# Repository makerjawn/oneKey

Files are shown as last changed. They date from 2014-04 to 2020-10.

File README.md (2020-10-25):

jawnWare: oneKey (obsolete, check forked)
===========

jawnWare_8 

Project Focus
-------------------
Developing a low-cost (<$2) and accessible derivative of the MaKey MaKey so that it can be sustainably deployed via workshops at various library branches. 

The aim is to introduce youth in underserved/low-income communities to making hardware that they can then tinker/play/make with. It's adressing the question "Can I take this home?" and the inability for youth to use take projects using digital media tools such as the MaKey MaKey home.

In participating in this process we hope for them to take more ownership of their tools. We're also trying to adress wether or not the library and its participants can make their own tools for learning via desktop manufacturing and production methods.

So what is a MaKey MaKey?
-------------------
From Sparkfun's [*MaKey MaKey Documentation*](https://github.com/sparkfun/makeymakey):

*"Using the MaKey MaKey you can make anything into a key (get it?) just by connecting a few alligator clips. The MaKey MaKey is an invention kit that tricks your computer into thinking that almost anything is a keyboard. This allows you to hook up all kinds of fun things as an input."*

**How does it work?**

*"The MaKey MaKey uses high resistance switching to detect when you've made a connection even through materials that aren't very conductive (like leaves, pasta or people). This technique attracts noise on the input, so a moving window averager is used to lowpass the noise. The on-board ATMega32u4 communicates with your computer using the Human Interface Device (HID) protocol which means that it can act like a keyboard or mouse."*

Methods
-------------------
The original oneKey uses a vinyl cutter and 3M copper tape to make a low-barrier and low-cost method for creating traces to solder onto. If working indoors take precautions with ventilalation etc. Working currently on a PCB kit version.

Need for the oneKey
-------------------
* 3M Copper Tape (used to be much cheaper, working on a thinner tape iteration.) ([Buy](http://www.amazon.com/inch-yds-Copper-Foil-Tape/dp/B00CBPM9RY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) | [HowTo](http://www.kobakant.at/DIY/?p=1132))
* Attiny85 ([Buy](http://www.digikey.com/product-detail/en/0/ATTINY85-20PU-ND) | [HowTo](about:blank))
* Attiny85 Standoff/ IC DIP Socket([Buy](http://www.digikey.com/product-detail/en/0/ATTINY85-20PU-ND) | [HowTo](about:blank))
* Resistors: 2x [68 ohm](http://www.digikey.com/product-detail/en/0/S68HCT-ND) , 1x [1.5K](http://www.digikey.com/product-detail/en/0/S1.5KHCT-ND), 1x [1M ohm](http://www.digikey.com/product-detail/en/0/CF14JT1M00CT-ND).
* Zener Diode ([Buy](http://www.digikey.com/product-detail/en/0/1N4148DICT-ND) | [HowTo](about:blank))
* USB Cable ([Buy](http://www.amazon.com/Eversame-Colorful-Hi-Speed-Universal-Phones-Black/dp/B00OC6WR22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) | [HowTo](about:blank))
* Vinyl Cutter (All makes/models work) ([Buy](http://www.amazon.com/Vinyl-Cutter-USCutter-34in-BUNDLE/dp/B00CDQGCTW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) | [HowTo](about:blank))
* Soldering Iron ([Buy](about:blank) | [HowTo](about:blank))
* Needle Nose Pliers ([Buy](about:blank) | [HowTo](about:blank))
* Wire Cutter ([Buy](about:blank) | [HowTo](about:blank))
* Wire Stripper ([Buy](about:blank) | [HowTo](about:blank))
* Tiny AVR Programmer or Equivalent ([Buy](https://www.sparkfun.com/products/11801) | [HowTo](https://learn.sparkfun.com/tutorials/tiny-avr-programmer-hookup-guide/))

Repository Contents
-------------------
* **/Firmware** - Arduino Files+
* **/Hardware** - All design files (EAGLE, FRITIZING, AI+)
* **/Instructon** - Instructors materials
* **/Supplies** - Previous part orders

Variations
----------------
**Vinyl Cut Copper Tape** 

oneKey Vinyl 

This build requres soldering and takes an hour to construct. The tape can be tricky to adhere to a substrate, but for all intents and purposes IT WORKS!

Requires the installation of the Digispark Arduino IDE to upload and run code from /Firmware.
All vector files needed for vinylcutting reside in /Hardware.

**PCB(REV.1)**  

PCB

PCB2

Looking to make a PCB kit, currently waiting for PCB to be milled. See the Eagle Schematics and Board files in /Hardware.

**Quick-build(Still in Development)**  
This build is solderless, can be built in less than an hour.

Links/Sources
-------------------
* [Digispark](http://digistump.com/products/1)
* [Digispark IDE](about:blank)
* [Digispark Clone](about:blank)
* [BhavyaShukla - Makey-makey-using-arduino-uno-r3-Multiple-input](https://github.com/BhavyaShukla/Makey-makey-using-arduino-uno-r3-Multiple-inputs-)
* [Moving Avarage Library](https://github.com/BhavyaShukla/Makey-makey-using-arduino-uno-r3-Multiple-inputs-)
* [JoyLab's/Sparkfun's - MaKey MaKey](https://github.com/sparkfun/makeymakey)
* [avrdude tutorials](https://learn.adafruit.com/usbtinyisp/avrdude)

toDo
-------------------
* easier peeling
* solderless
* remove usb cable
* ~~thruhole prototype~~
* non-digispark
* attiny45?
* find other hardware thruhole prototype
* do outreach, find other ppl who want this

brief history
-------------------
To date two iterations of the one input MaKey MaKey derivative, "MaKey MaKey MaKey", or officially "oneKey" for short, have been deployed. The first generation proved that youth could make, hack, and play with their own hardware. After various form and material explorations as well as a circuit redesign it is currently in its second phase. The new design is easier to handle, the cost per unit has dropped from $7 to $1.30, it's quicker to make, and there is still much more to refine.

people
-------------------
* bk brandonklevence@gmail.com
* the Maker Jawn Initiative info@makerjawn.org

License Information
-------------------
The hardware is released under [Creative Commons Share-alike 3.0](http://creativecommons.org/licenses/by-sa/3.0/).  
All other code is open source hardware so please feel free to do anything you want with it; 
you buy me a beer if you use this and we meet someday ([Beerware license](http://en.wikipedia.org/wiki/Beerware)).
Please support [Digispark](https://github.com/sparkfun/makeymakey) and [JoyLabs](https://github.com/sparkfun/makeymakey) and buy their products if you decide to remix. Without their creativity and ingenuity this project would never have happened.

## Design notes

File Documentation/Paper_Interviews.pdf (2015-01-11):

Vince, age 9, a participant in my workshops at the Kensington Branch.

B So, What did we make?
V A MaKey MaKey, wooh!
B Cool right?
V Look at this, nobody knows how to do this..
B What did we put in it?
V Wires and wires, and wires .. And MaKey MaKey hot sauce(solder). B And then what did we use?
V A light. And then a long wire that plugs it into the computer. Ta DA! **Showing off the MaKey MaKey MaKey**
B So what’s going on here?
V When you touch the playdoh it does stuff on the computer.
B Do you remember what it’s doing?
V Being a keyboard!
**With minecraft the game on screen, he breaking down blocks of sand and digging a ditch. V The MaKey MaKey, it cuts!
V I am so happy to take this home and break my computer!
V Can we make another?
B No, you already have one dude!
V I want to make more, can I help other kids make them here? I should get my friends from school to come to make more MaKey MaKeys!

After playing a Canabalt with Ice cream where you lick your ice cream to interact with the game on screen.(using the MaKey MaKey)

B So what do you think?
O That’s pretty weird.
B What is weird about it?
O it's kinds weird because you're licking the ice cream...
B How did you control it?
O You moved it with your tongue. Your tongue is the controller. B What did you think about the game?
O It’s like Mario, but faster.

This is a video interview about a magnetic maze prototype we made at the Village of Arts and Humanites. Donnie filmed and helped correct or as questions of Mykal who was demonstrating his creation.

M Hi I’m Mike
B How old are you?
M I’m 8.
B Where do you live?
M On the north side of the street. B And what do we have here?
M We have a Magnetic Maze.
B Sweet.
M Now look, it might come off, but don’t be mad.
B Ok?
M Ya see, if I come to this playdoh here with the magnet, this light comes on and off? B So Mykal, can you explain the circuit to me, the positive and the negative?
M The yellow is the postitive.
D Posittive Mykal
M Yellow is posittive and red is negative.
B And what about the batter and LEDs?
M This is my LED (points to battery).
D No no!
M This is my LED and this is my battery.(correctly identifies)
B And what about your glasses?
M This is them! (points) They light up when you hit the maze.
D Basically its an LED light, and we have a Maze. So when you're playing the maze and you've hit a wall or something will glow of to signify you and notificate you that you've hit the wall. So we’ve made a sample and soon we’ll be able to make something like this, but huge. M Soon we’ll be able to make something else, like this!
B Cool!
D Yeah, what’s your name?
M I’m Mykal
B I’m bk.
D and I’m Donnie, we out!

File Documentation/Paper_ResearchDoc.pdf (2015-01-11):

Name:
bk // Brandon Klevence

Contact:
bklevence@uarts.edu // klevenceb@freelibrary.org @bklvnc // @makerjawn

Blog:
www.makerjawn.org

Links:
https://www.diigo.com/user/bklvnc

Area(s) of Interest:
Informal Education / Participatory Design of Interactive Installations
/ Getting people making with electronics

Contextual Brief:
I will be implementing young adult programming at the Kensington Free Library Branch while overseeing similar programming at that Parkway Central Branch. Our focus is to improve digital skills and literacy of our library-goers through guided learning, exploration, workshops, and eventually collaboration on participatory design projects. This is a second round of implementing this type of programming. We’re very interested in how to document our work and share it online. Specifically methods of getting our young-adults to document and talk about their own work.
My focus in particular will be creating kits to encourage exploration of various concepts and skills related to learning about and making electronic interactives or installations.

Keywords:
connected learning, digital literacy, electronics, making, maker, library, resources, underserved, after-school, teens, programming, computing, technology, understanding, play, exploration, workshops, etextiles, crafting, flat, teaching, guided learning, participatory design, eorigami, hi-low tech, mit, makered, digital media, internet, proficiency, sharing, collaborating, exposure, computation, programming, kids, youth, arts, craft, empowering, failure,

What am I looking for?
- peer reviewed research
- case studies
- other precedents of making in libraries
- educational kits for exploring topics/play
- scaffolded learning plans. see: (http://learn.sparkfun.com/)
- tools for guiding making/learning in workshops or public places
- suggestions for teaching different age groups, needs and best practices

Case, Amber. An Illustrated Dictionary of Cyborg Anthropology. N.p.: n.p., n.d.Http://cyborganthropology.com/store/. Web.
Dewey, John. Experience and Education. New York: Macmillan, 1938. Print.
Anderson, Chris. Makers: The New Industrial Revolution. New York: Crown Business, 2012. Print.
Rushkoff, Douglas, and Leland Purvis. Program or Be Programmed: Ten Commands for a Digital Age. Berkeley, CA: Soft Skull, 2011. Print.
Brosterman, Norman, and Togashi. Inventing Kindergarten. [New York, N.Y.]: H.N. Abrams, 1997. Print.
Murakami, Haruki, and Jay Rubin. Norwegian Wood. New York: Vintage International, 2000. Print.
Plowman, Lydia, Christine Stephen, and Joanna McPake. Growing up with Technology: Young Children Learning in a Digital World. London: Routledge, 2010. Print.

Itō, Mizuko. Hanging Out, Messing Around, and Geeking Out: Kids Living and Learning with New Media. Cambridge, MA: MIT, 2010. Print.

Nilsson, Elisabet M. "The Making of a Maker-space for Open Innovation, Knowledge Sharing, and Peer-to-peer Learning." FUTURE LEARNING SPACES. Helsinki: Aalto University, 2011. 293-98. Print.

Petrovich, Dushko, and Roger White. Draw It with Your Eyes Closed: The Art of the Art Assignment. Brooklyn, NY: Paper Monument, 2012. Print.

Allen, Felicity. Education. London: Whitechapel Gallery, 2011. Print.

https://pittsburghkids.org/exhibits/makeshophttp://www.libraryasincubatorproject.org/?p=11684

http://www.pensacolamesshall.org/explore/mess-kits/

Fellowship Forum/Blog:
http://www.hastac.org/

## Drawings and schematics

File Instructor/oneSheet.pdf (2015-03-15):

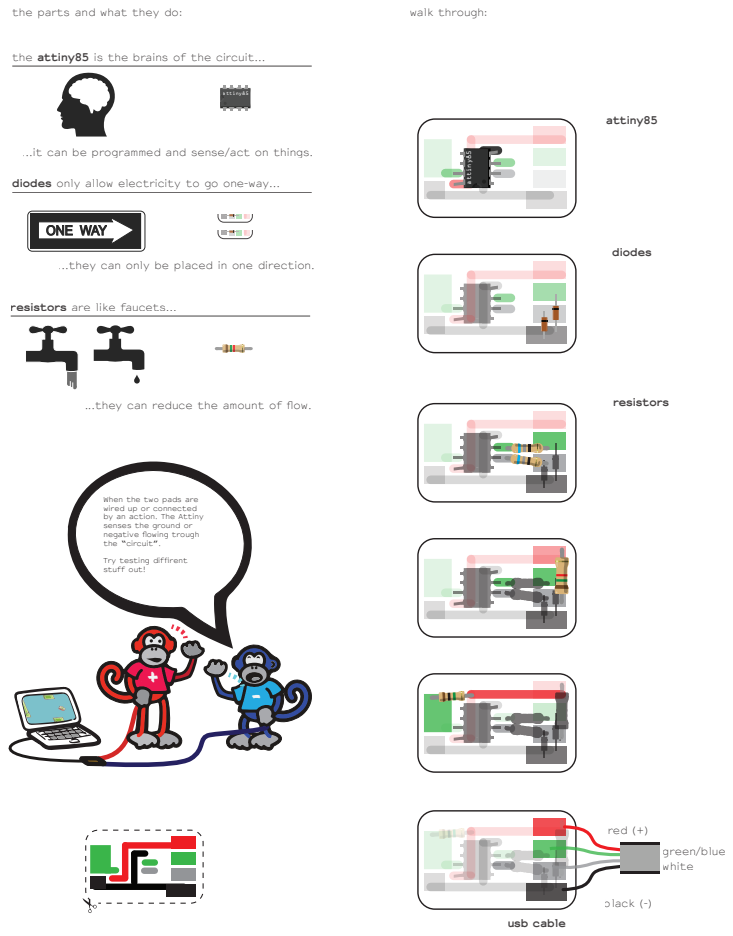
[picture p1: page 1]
ONE WAY; the parts and what they do:; walk through:; attiny85; attiny85 attiny85 attiny85 attiny85 attiny85; diodes; resistors; usb cable; black (-); red (+); green/blue white

the attiny85 is the brains of the circuit...

...it can be programmed and sense/act on things.

diodes only allow electricity to go one-way...

...they can only be placed in one direction.

resistors are like faucets...

...they can reduce the amount of flow.

When the two pads are
wired up or connected
by an action. The Attiny
senses the ground or
neJatLYe flowLnJ trouJh
the “circuit”.
7ry teVtLnJ dLfrent
stuff out!

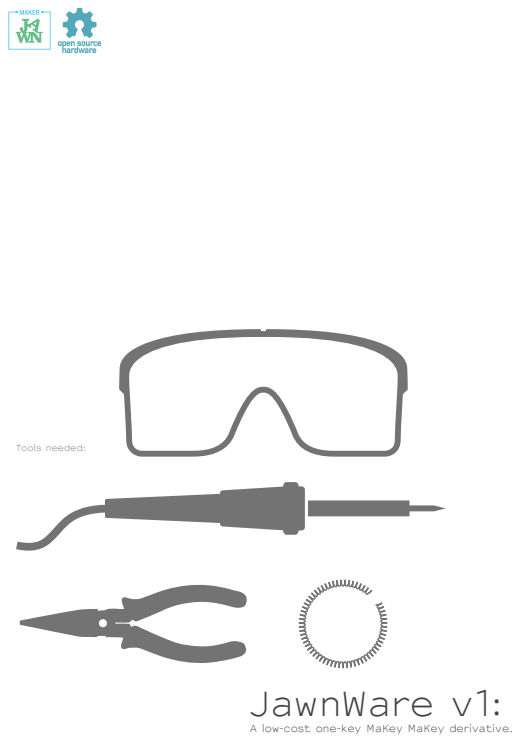
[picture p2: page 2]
JawnWare v1:; Tools needed:

A low-cost one-key MaKey MaKey derivative.

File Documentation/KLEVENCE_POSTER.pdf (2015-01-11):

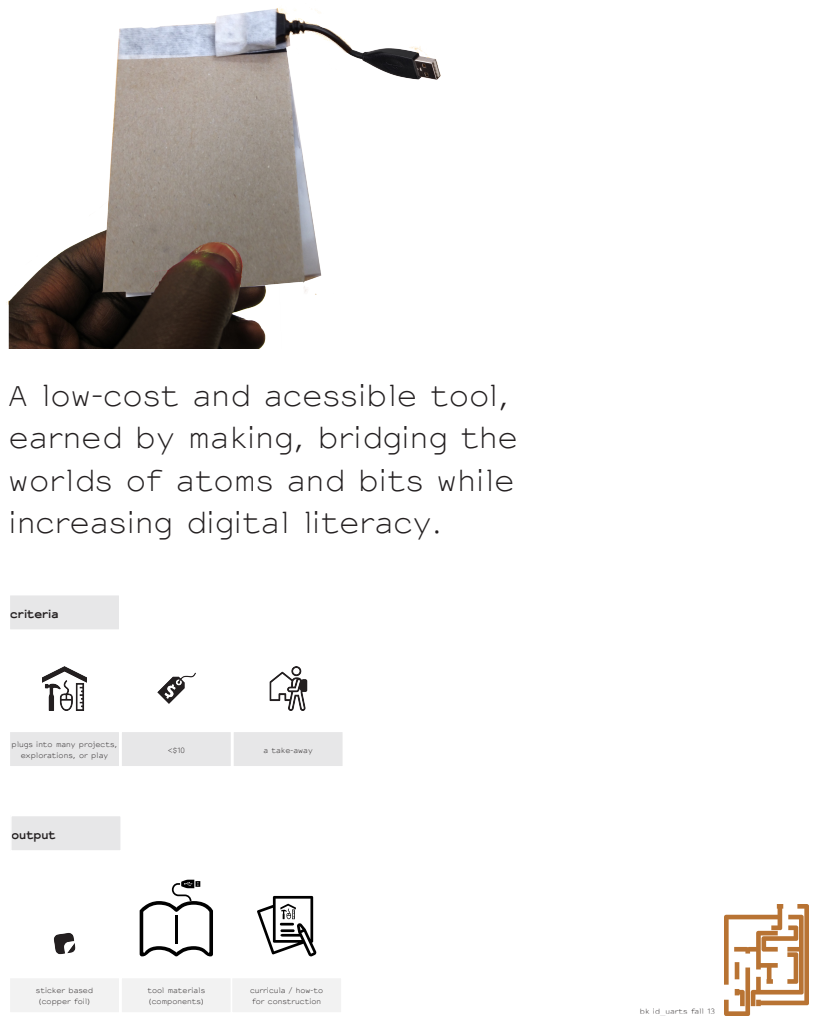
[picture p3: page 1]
explorations, or play; a take-away; criteria; sticker based (copper foil); tool materials (components); output; bk id_uarts fall 13

A low-cost and acessible tool,
earned by making, bridging the
worlds of atoms and bits while
increasing digital literacy.

plugs into many projects,

curricula / how-to
for construction

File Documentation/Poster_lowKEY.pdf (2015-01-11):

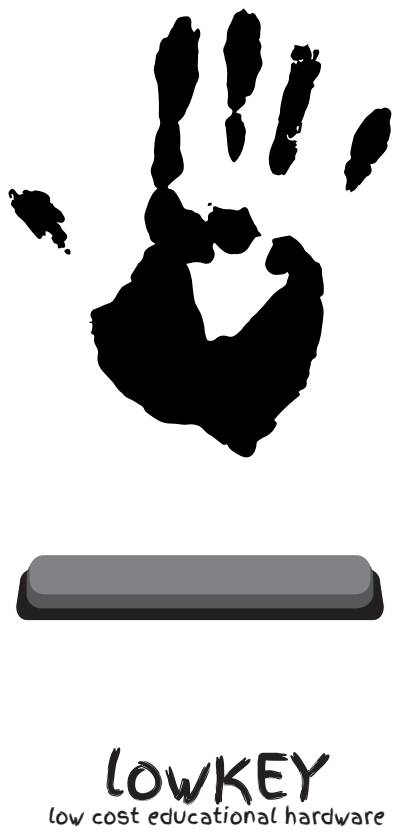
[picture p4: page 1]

lowKEY low cost educational hardware

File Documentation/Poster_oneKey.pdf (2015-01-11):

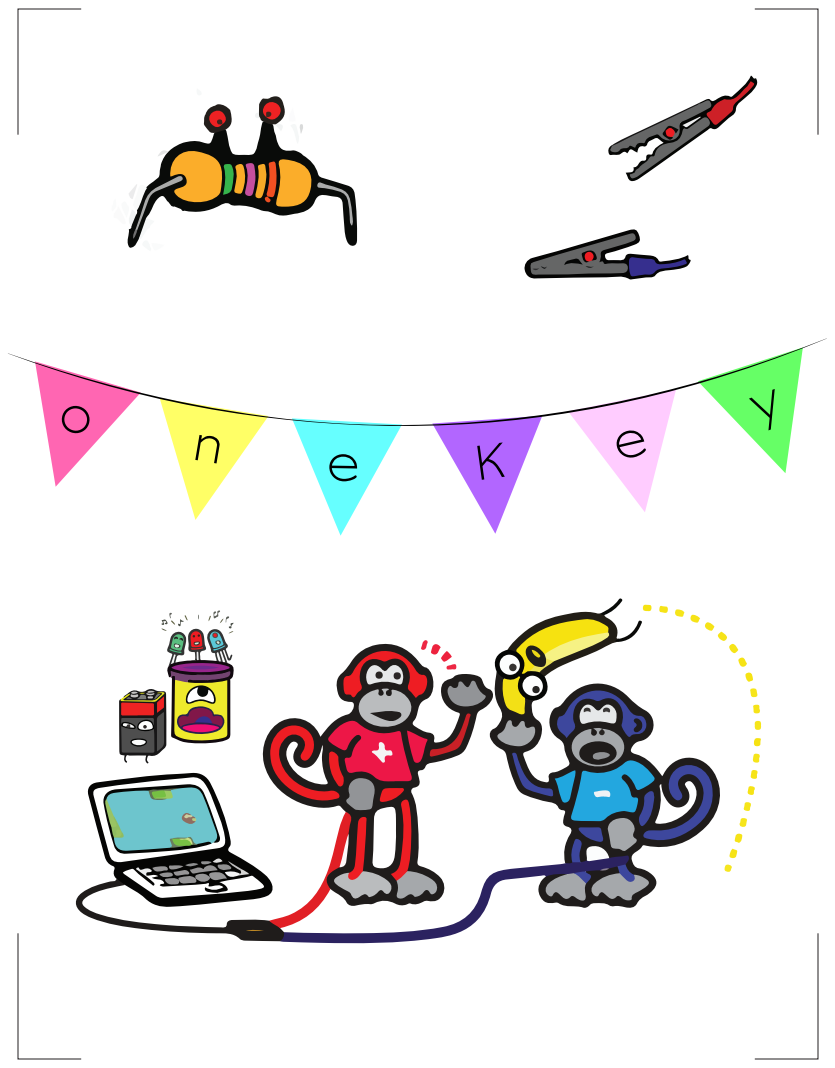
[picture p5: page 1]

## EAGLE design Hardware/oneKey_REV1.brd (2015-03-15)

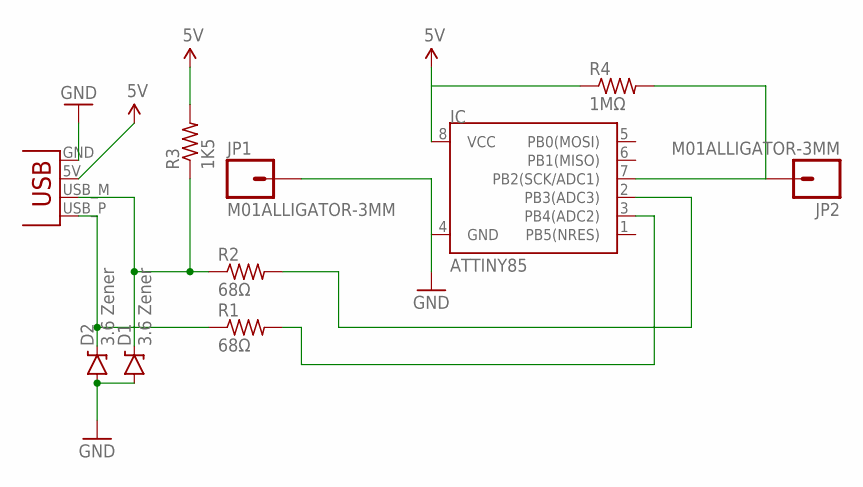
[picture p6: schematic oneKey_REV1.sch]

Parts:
D1, D2: 3.6 Zener; DIODE-ZENER
IC: ATTINY85; DIP08
JP1, JP2: M01ALLIGATOR-3MM; 1X01_ALLIGATOR_3MM
R1, R2: 68Ω; 0204/7
R3: 1K5; 0204/7
R4: 1MΩ; 0204/7
X1: USBPCB; USB-A-PCB

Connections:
5V: IC.8 (VCC), R3.2, R4.1, X1.5V (VBUS)
GND: D1.P$2 (A), D2.P$2 (A), IC.4 (GND), JP1.1@0, JP1.1@2, X1.GND
unnamed: IC.2 (PB3(ADC3)), R2.2
unnamed: IC.7 (PB2(SCK/ADC1)), JP2.1@0, JP2.1@2, R4.2
unnamed: IC.3 (PB4(ADC2)), R1.2
unnamed: D1.P$1 (C), R2.1, R3.1, X1.USB_M (D-)
unnamed: D2.P$1 (C), R1.1, X1.USB_P (D+)

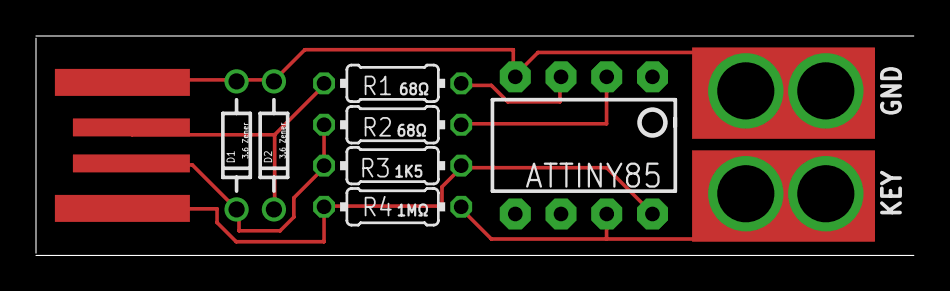
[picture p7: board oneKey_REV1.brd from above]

Board: 2 copper layers, 48.8 x 12.2 mm, 11 parts (1 on the bottom side), 7 nets.

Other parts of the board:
U$4: OSHW-LOGO-S

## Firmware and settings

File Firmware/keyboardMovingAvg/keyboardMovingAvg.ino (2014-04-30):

//29.04.14
//http://github.com/makerjawn/jawnware
//info@makerjawn.org
//A low-cost one input MaKey MaKey derivative.

//top secret launch codes
//avrdude -c usbtiny -p attiny85 -b 19200 -U flash:w:micronucleus-1.03-2secs.hex -F
//avrdude -c usbtiny -p attiny85 -U lfuse:w:0xE1:m -U hfuse:w:0xDD:m -U efuse:w:0xFE:m


#include "DigiKeyboard.h"
#include <MovingAvarageFilter.h>

int led(0); //I have hidden an LED blink on input

MovingAvarageFilter movingAvarageFilter(20);

boolean check = false;

void setup() {

  pinMode(led,OUTPUT); 
  pinMode(7,INPUT); //Sense PIN 
}

void loop() {

  // declare input and output variables

  float input = analogRead(7); // without a real input, looking at the step respons (input at unity, 1)

  float output = 0;

  output = movingAvarageFilter.process(input);


  if (output < 400) { // you can change this parameter to fine tune the sensitivity
    if (!check){
      digitalWrite(led, LOW);
      //Other key presses:
      //Up
      //Down
      //Left
      //Right
      //Space
      //Enter
      //Key Press:
      DigiKeyboard.sendKeyStroke(KEY_SPACE);
      check = !check;
    }
  }

  if (output >900) {
    digitalWrite(led, HIGH);
    if (check){
      check = !check;
    }
  }
}

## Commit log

2014-02-25 initial upload
    [MMMv1.fzz, MMMv1_input.fzz, MMMv1_keyboard.fzz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]
2014-04-28 cleaning house
    [MMMv1.fzz, MMMv1_input.fzz, MMMv1_keyboard.fzz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]
2014-04-30 updating all the things
    [11-5.fzz, 11-5.sch, MMMv1.fzz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]
2015-01-11 Restructure
    Documentation and Archive of iterations
    [11-5.fzz, 11-5.sch]
2015-01-11 Organizing
    Documentation Updates, Archiving of Iterations, and much more. Will be
    updating readme soon.
    [11-5.fzz, 11-5.sch]
2015-01-11 Instructors Materials
    See pdf
2015-03-15 update rm, eagle files, etc
    [11-5.sch, incomplete.fzz, oneKey_REV1.brd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]
2015-04-22 usb sample
    have found way cheaper lots in the past

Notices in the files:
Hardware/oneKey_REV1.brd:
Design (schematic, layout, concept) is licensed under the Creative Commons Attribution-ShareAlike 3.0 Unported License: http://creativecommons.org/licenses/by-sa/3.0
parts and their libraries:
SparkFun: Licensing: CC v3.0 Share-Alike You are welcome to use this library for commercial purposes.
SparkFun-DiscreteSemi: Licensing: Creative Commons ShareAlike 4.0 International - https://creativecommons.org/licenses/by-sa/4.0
